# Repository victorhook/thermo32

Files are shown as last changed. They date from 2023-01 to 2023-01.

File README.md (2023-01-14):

# THERMO32
This repository contains the design and source code for a smart temperature monitoring system. At it's core, the THERMO32 is a PCB which contains an [ESP32-C3](https://www.espressif.com/en/products/socs/esp32-c3) microcontroller and a [STS35](https://sensirion.com/products/catalog/STS35-DIS/) temperature sensor. The PCB comes with a USB-mini to power it, and contains a button that allows you to set it into setting-mode, where you can configure the settings through its web interface.

## Startup
When the device boots, it loads the settings and tries to connect to a WiFi with the stored WiFi SSID and password. If the device fails to connect to a WiFi within a given amount of time, it starts as an access point instead, and starts the server mode (see below) which you can connect to and configure its settings.

## Server mode
When the device is in server mode you can configure the settings.

The device can enter server mode in two ways:
1. If it fails to connect to the WiFi SSID in its configuration.
2. By holding down the button while you power on the device.

Once the device is in server mode, you can configure its settings through its webserver that you can access on port 80.

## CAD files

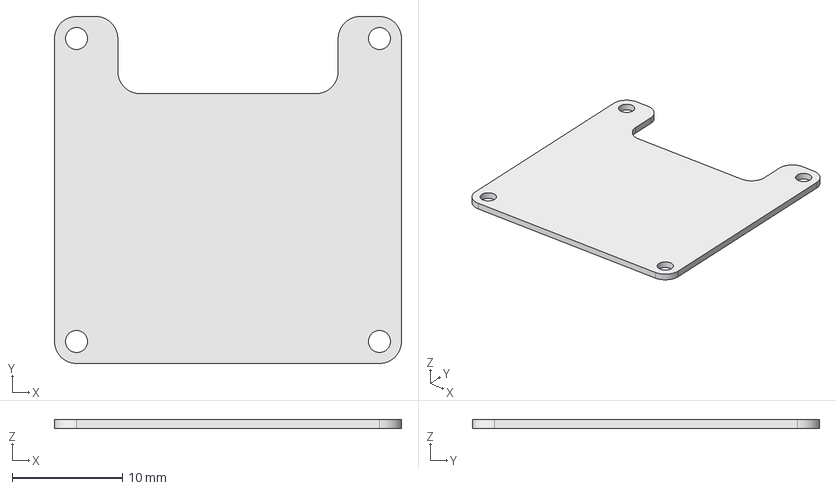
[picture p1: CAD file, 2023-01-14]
cad/temperature-monitor-rev-a/Pcb.FCStd
31.5 x 31.5 x 0.8 mm

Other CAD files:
cad/temperature-monitor-rev-a/Pcb.dxf

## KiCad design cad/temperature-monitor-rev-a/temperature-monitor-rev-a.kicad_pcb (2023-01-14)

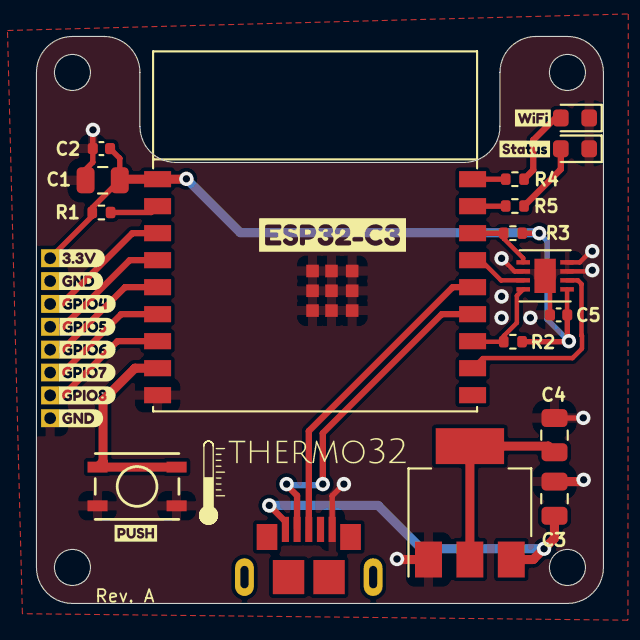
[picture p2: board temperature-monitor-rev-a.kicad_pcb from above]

Board: 2 copper layers, 31.5 x 31.5 mm, 30 parts (0 on the bottom side), 21 nets.

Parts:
C1, C3, C4: 10uF; C_0805_2012Metric
C2: 1uF; C_0402_1005Metric
C5: 100nF; C_0402_1005Metric
D1, D2: LED; LED_0603_1608Metric
J1: USB3075-30-A; USB3075-30-A_No_silk
J2: Conn_01x08; PinHeader_1x08_P1.27mm_Vertical_No_silk
R1: 10k; R_0402_1005Metric
R2, R3: 2.2k; R_0402_1005Metric
R4, R5: 330; R_0402_1005Metric
SW1: BOOT; PTS815
U1: ESP32-C3-WROOM-02
U2: AMS1117-3.3; SOT-223-3_TabPin2
U3: STS35-DIS; STS35-DIS_temp_sensor
kibuzzard-63BBD8F6: G***; kibuzzard-63BBD8F6
kibuzzard-63BBD915: G***; kibuzzard-63BBD915
kibuzzard-63BBDC2F: G***; kibuzzard-63BBDC2F
kibuzzard-63BBE3A0: G***; kibuzzard-63BBE3A0
kibuzzard-63BBE3A5: G***; kibuzzard-63BBE3A5
kibuzzard-63BBE3D2: G***; kibuzzard-63BBE3D2
kibuzzard-63BBE32B, kibuzzard-63BBE32B#2: G***; kibuzzard-63BBE32B
kibuzzard-63BBE39B: G***; kibuzzard-63BBE39B
kibuzzard-63BBE312: G***; kibuzzard-63BBE312
kibuzzard-63BBE366: G***; kibuzzard-63BBE366
kibuzzard-63BBE393: G***; kibuzzard-63BBE393

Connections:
+3.3V: C1.1, C2.1, C5.1, J2.1, R1.1, R2.1, R3.1, U1.1 (3V3), U3.5 (VDD)
+3V3: C4.1, U2.2 (VO)
/BUTTON: SW1.1, SW1.2, U1.8 (GPIO9)
/GPIO4: J2.3, U1.3 (GPIO4/ADC1_CH4)
/GPIO5: J2.4, U1.4 (GPIO5/ADC2_CH0)
/GPIO6: J2.5, U1.5 (GPIO6)
/GPIO7: J2.6, U1.6 (GPIO7)
/GPIO8: J2.7, U1.7 (GPIO8)
/LED_BLUE: R4.2, U1.18 (GPIO0/ADC1_CH0/XTAL_32K_P)
/LED_RED: R5.2, U1.17 (GPIO1/ADC1_CH1/XTAL_32K_N)
/SCL: R2.2, U1.12 (GPIO21/U0TXD), U3.4 (SCL)
/SDA: R3.2, U1.16 (GPIO2/ADC1_CH2), U3.1 (SDA)
/TEMP_ALERT: U1.15 (GPIO3/ADC1_CH3), U3.3 (ALERT)
/TEMP_NRESET: U1.11 (GPIO20/U0RXD), U3.6 (NRESET)
/USB+: J1.3 (D+), U1.14 (GPIO19/USB_D+)
/USB-: J1.2 (D-), U1.13 (GPIO18/USB_D-)
GND: C1.2, C2.2, C3.2, C4.2, C5.2, D1.1 (K), D2.1 (K), J1.5 (GND), J2.2, J2.8, SW1.3 (K), SW1.4 (A), U1.9 (GND), U1.19 (GND), U2.1 (GND), U3.2 (ADDR), U3.7 (R), U3.8 (VSS), U3.9 (VSS)
unnamed: C3.1, J1.1 (VBUS), U2.3 (VI)
unnamed: D1.2 (A), R4.1
unnamed: D2.2 (A), R5.1
unnamed: R1.2, U1.2 (EN/CHIP_PU)

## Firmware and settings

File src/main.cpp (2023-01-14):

#include <Arduino.h>
#include "wifi_handler.h"
#include "settings_handler.h"
#include "led_handler.h"
#include "measurement.h"


typedef enum {
  MODE_NORMAL,
  MODE_SET_CONFIGURATION,
} thermo32_mode_t;

#define CONNECT_TO_WIFI_TIMEOUT_S 30

thermo32_mode_t mode = MODE_NORMAL;
WiFiHandler wifi;
SettingsHandler settings_handler;


void setup() {

  switch (esp_sleep_get_wakeup_cause()) {
    case ESP_SLEEP_WAKEUP_TIMER:
      break;
    default:
      break;
  }

  led_init(&led_blue);
  led_init(&led_red);
  Serial.begin(115200);

  Serial.println("Initializing sensors...");
  initSensors();

  // Once we've booted, we'll try to find a WiFi to connect to.
  Serial.println("Initializing WiFi...");
  led_set(&led_blue, LED_MODE_BLINK_0_5_HZ);
  if (!wifi.connectToWiFi(CONNECT_TO_WIFI_TIMEOUT_S)) {
    // Failed to connect to WiFi.
    led_set(&led_blue, LED_MODE_BLINK_2_HZ);
    wifi.startAsAccessPoint();
    mode = MODE_SET_CONFIGURATION;
  }

  if (mode == MODE_SET_CONFIGURATION) {
    // We're not going to do any measurements, but instead start a server
    // so the user can configuration some settings.
    led_set(&led_blue, LED_MODE_ON);
    settings_handler.startServer();

    // Once the settings-handler server is finished, we'll restart.
    esp_restart();
  }

}

void loop() {
  const settings_t* settings = settings_handler.loadSettings();
  measurement_t measurement;
  takeMeasurement(&measurement);
  publishMeasurement(&measurement, settings);

  // Go to sleep for X minutes.
  esp_sleep_enable_timer_wakeup((settings->min_between_pub * 60) * 1e6);
  esp_deep_sleep_start();
}

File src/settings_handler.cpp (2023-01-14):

#include "settings_handler.h"
#include "SPIFFS.h"
#include "ESPAsyncWebServer.h"

const char* settings_path = "settings";
const settings_t default_settings = {

};
settings_t settings;

static bool waitForRestart = true;

// -- Helper methods -- /
void _storeSettings(const settings_t* settings) {
    File file = SPIFFS.open(settings_path, "w", true);
    size_t bytes_written = file.write((uint8_t*) settings, sizeof(settings_t));
    file.close();

    if (bytes_written != sizeof(settings_t)) {
        // TOOD?
    }
}

void _loadSettings(settings_t* settings) {
    File file = SPIFFS.open(settings_path, "r");
    size_t bytes_read = file.readBytes((char*) settings, sizeof(settings_t));
    file.close();

    if (bytes_read != sizeof(settings_t)) {
        // TOOD?
    }
}

static void setSettingParamString(char* str, AsyncWebServerRequest *request, const char* name);
static void setSettingParamU16(uint16_t* u16, AsyncWebServerRequest *request, const char* name);
// -- Http request handlers -- //
static void onNotFound(AsyncWebServerRequest *request);
static void onIndex(AsyncWebServerRequest *request);
static void onSettings(AsyncWebServerRequest *request);
static void onRestart(AsyncWebServerRequest *request);


SettingsHandler::SettingsHandler() {

}

void SettingsHandler::startServer() {
    //_settings = settings;
    AsyncWebServer server(SETTINGS_SERVER_PORT);
    server.on("/", HTTP_GET, onIndex);
    server.on("/settings", HTTP_POST, onSettings);
    server.on("/restart", HTTP_POST, onRestart);
    server.onNotFound(onNotFound);
    server.begin();

    while (waitForRestart);
}

const settings_t* SettingsHandler::loadSettings() {
    SPIFFS.begin();
    if (!SPIFFS.exists(settings_path)) {
        _storeSettings(&default_settings);
    }

    _loadSettings(&settings);
    return &settings;
}

// -- Private -- //

// Helpers
static void setSettingParamString(char* str, AsyncWebServerRequest *request, const char* name) {
    if (request->hasParam(name)) {
        AsyncWebParameter* param = request->getParam(name);
        memcpy(str, param->value().c_str(), param->size());
    }
}

static void setSettingParamU16(uint16_t* u16, AsyncWebServerRequest *request, const char* name) {
    if (request->hasParam(name)) {
        AsyncWebParameter* param = request->getParam(name);
        *u16 = param->value().toInt();
    }
}

static String processor(const String& var)
{
    if (var == "ssid") {
        return String(settings.wifi_ssid);
    } else if (var == "password") {
        return String(settings.wifi_pass);
    } else if (var == "wifi_timeout") {
        return String(settings.wifi_connect_timeout);
    } else if (var == "device_id") {
        return String(settings.device_id);
    } else if (var == "mqtt_broker_ip") {
        return String(settings.mqtt_broker_ip);
    } else if (var == "mqtt_broker_port") {
        return String(settings.mqtt_broker_port);
    } else if (var == "mqtt_topic") {
        return String(settings.mqtt_topic);
    } else if (var == "pub_freq") {
        return String(settings.min_between_pub);
    }

  return String();
}

// Http request handlers
static void onNotFound(AsyncWebServerRequest *request) {
    request->send(404, "text/plain", "Not found");
}
static void onIndex(AsyncWebServerRequest *request) {
    _loadSettings(&settings);
    request->send(SPIFFS, "/index.html", "text/plain", false, processor);
}
static void onSettings(AsyncWebServerRequest *request) {
    settings_t settings;
    setSettingParamString(settings.wifi_ssid, request, "ssid");
    setSettingParamString(settings.wifi_pass, request, "password");
    setSettingParamU16(&settings.wifi_connect_timeout, request, "wifi_timeout");
    setSettingParamString(settings.device_id, request, "device_id");
    setSettingParamString(settings.mqtt_broker_ip, request, "mqtt_broker_ip");
    setSettingParamU16(&settings.mqtt_broker_port, request, "mqtt_broker_port");
    setSettingParamString(settings.mqtt_topic, request, "mqtt_topic");
    setSettingParamU16(&settings.min_between_pub, request, "min_between_pub");
    _storeSettings(&settings);
    _loadSettings(&settings);
    request->send(200, "text/plain", "Settings set OK");
}
static void onRestart(AsyncWebServerRequest *request) {
    request->send(200, "text/plain", "Restarting...");
    waitForRestart = false;
}

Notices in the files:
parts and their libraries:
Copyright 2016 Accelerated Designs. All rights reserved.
